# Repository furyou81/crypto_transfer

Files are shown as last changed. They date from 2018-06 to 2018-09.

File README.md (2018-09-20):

# crypto_transfer project

crypto transfert is a cryptocurrency payment terminal that we designed from scratch:
  - selecting the components and the PIC32
  - schematics and designing the PCB with Altium
  - coding the drivers (I2C, SPI, UART, ... ) in C with Mplab
  - coding the server with Node JS to interact with the Ethereum blockchain
  - coding a hotspot interface in PHP to configure the wifi on the payment terminal
  - proof of concept then prototyping
  - designing the case with Fusion 360

# Some pictures of the project

## Box
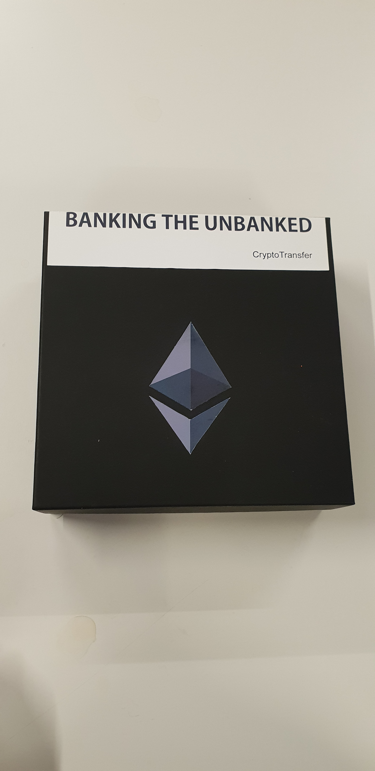
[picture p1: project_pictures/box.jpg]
Box


## Card
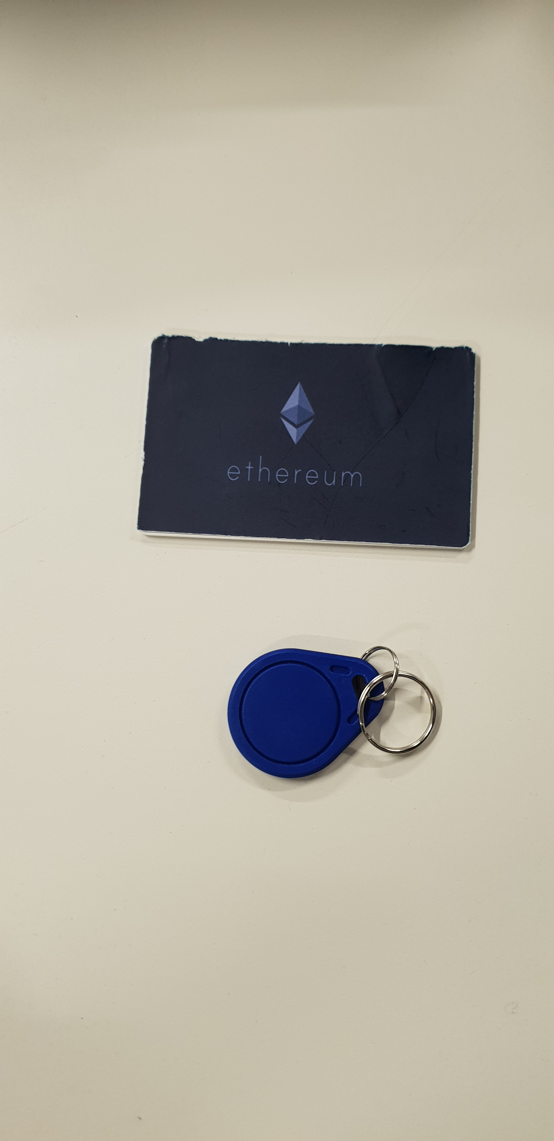
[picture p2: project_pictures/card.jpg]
Card


## Face
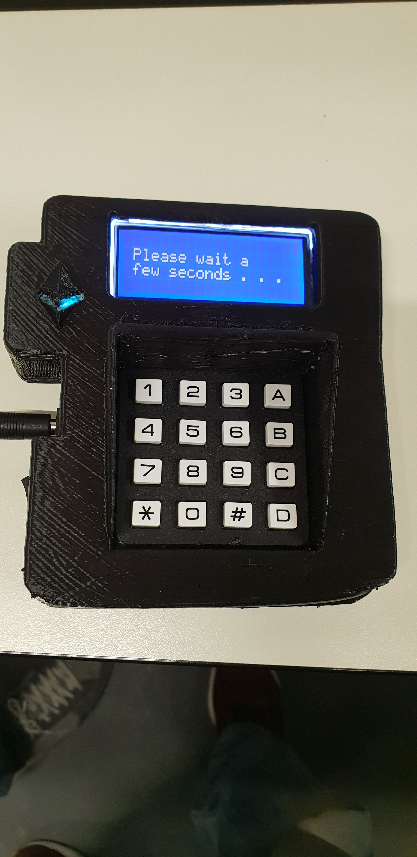
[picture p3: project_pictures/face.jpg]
Face


## Bottom
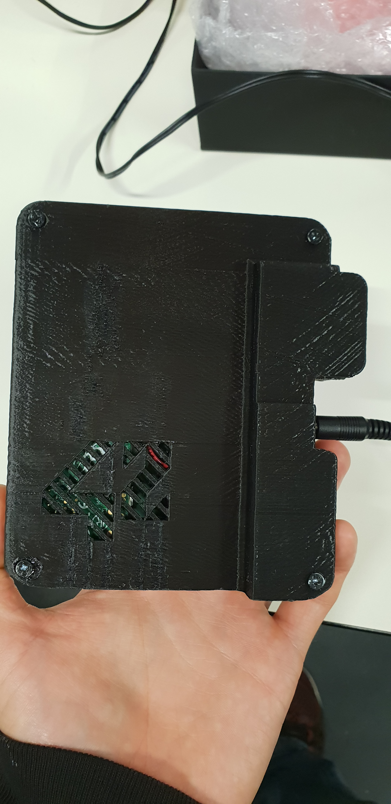
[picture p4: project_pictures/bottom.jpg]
Bottom


## Menu
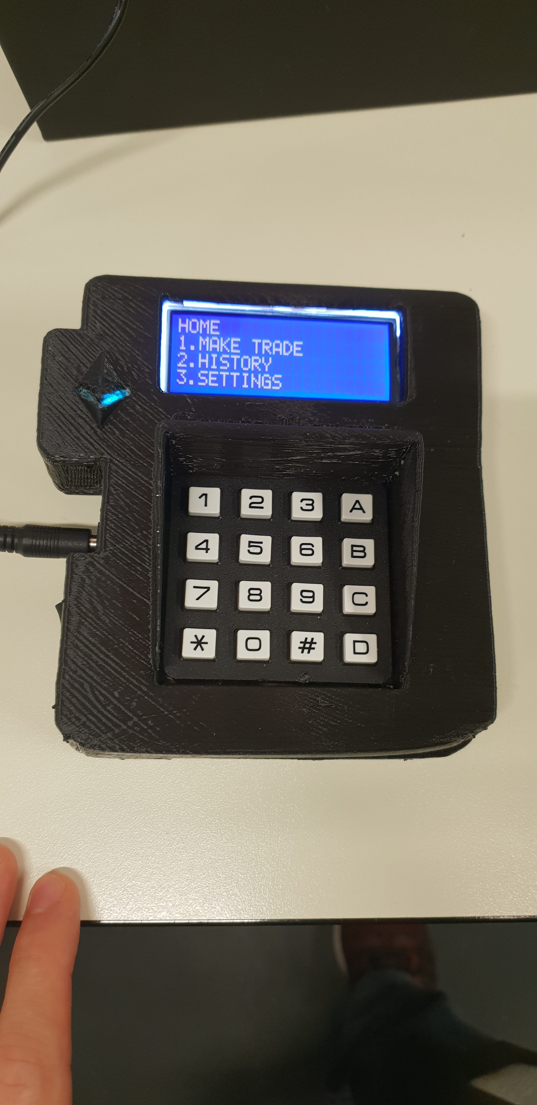
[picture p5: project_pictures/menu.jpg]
Menu


## PCB
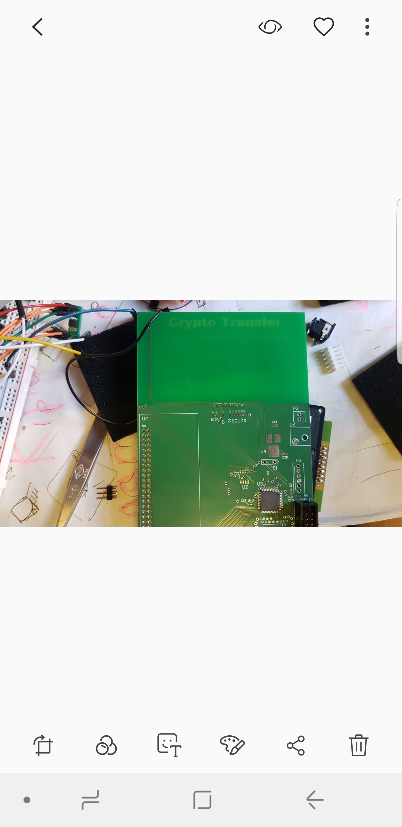
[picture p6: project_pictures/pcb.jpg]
PCB


## PCB with components
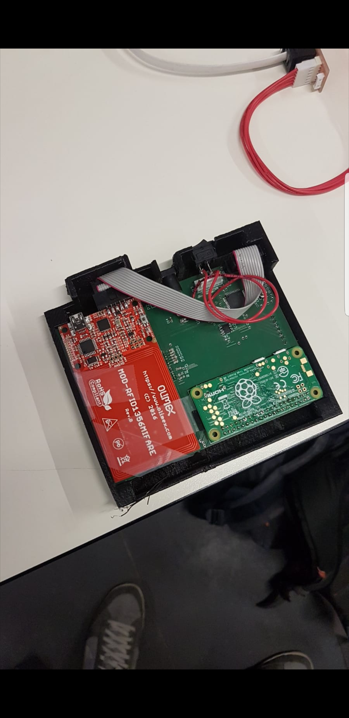
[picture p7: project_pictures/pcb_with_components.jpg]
PCB with components


## 3D design with Fusion 360
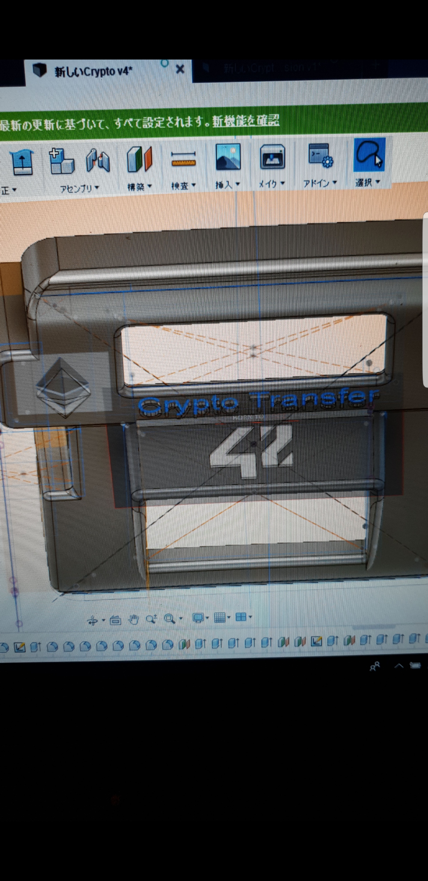
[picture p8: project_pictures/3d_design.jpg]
3D design


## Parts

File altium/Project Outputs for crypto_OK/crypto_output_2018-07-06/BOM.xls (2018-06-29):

Designator | Comment | FABRIQUANT | FOURNISSEUR | REF FABRIQUANT | REF FOURNISSEUR
P3 | ISCP | Molex | Farnell | 22-29-2061 | 1360134 | a commander
P4 | UEXT connector | OLIMEX | OLIMEX | MOD-RFID1356MIFARE | MOD-RFID1356MIFARE | a commander
U1 | ledRGB | MIDAS | FARNELL | AMB-MTB0-0A3A2 | 2401105
U2 | Flash | MICROCHIP | FARNELL | SST25VF010A-33-4C-SAE | 1829949
U3 | PIC32_1 | MICROCHIP | FARNELL | 2456845 | PIC32MX170F256D-I/PT | a commander
U4 | regulateur | TEXAS INSTRUMENTS | FARNELL | LM1117DT-3.3/NOPB | 1469048 | a commander
U5 | clavier | MULTICOMP | FARNELL | MCAK1604NBWB | 1182239
U6 | alim | Lumberg | Farnell | 1613 09 | 1216991 | a commander
U7 | Raspberry_pi_zero_w |  |  | X
C1 | Cap
C2 | Cap
C3 | Cap
C4 | Cap
C5 | Cap
C6 | Cap
C7 | Cap
C8 | Cap
C9 | Cap
C10 | Cap
C11 | Cap
C13 | Cap
C17 | Cap
C18 | Cap
C19 | Cap
C21 | Cap
Y1 | Quartz 8MHz | FOX ELECTRONICS | FARNELL | FOXSDLF/080-20 | 2063972 | a commander
P2 | lcd backlight | PHOENIX CONTACT | Farnell | 1725656 | 3041359 | a commander
P1 | LCD | MIDAS | FARNELL | MCCOG42005A6W-BNMLWI | 2218946
C14 | capacite ceramique | TDK | FARNELL | C1608X5R0J106K080AB | 2346889 | a commander
C20 | capacite ceramique | TDK | FARNELL | C1608X5R0J106K080AB | 2346889 | a commander
R1 | Res2
R2 | Res2
R3 | Res2
R4 | Res2
R5 | Res2
R6 | Res2
R7 | Res2
 | Connecteur RFID | AMP - TE CONNECTIVITY | FARNELL | 1761681-3 | 1772799 | a commander
 | Barrette clavier | MULTICOMP | FARNELL | 2211S-08G | 1593416 | a commander
 | Alimentation | XP POWER | FARNELL | ACM PLUG EU | 2674846 | a commander
 | Alimentation | XP POWER | FARNELL | ACM18US05 | 2671551 | a commander

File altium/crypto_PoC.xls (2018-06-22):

Designator | Comment | FABRIQUANT | FOURNISSEUR | REF FABRIQUANT | REF FOURNISSEUR
U1 | RFID | OLIMEX | FARNELL | MOD-RFID1356MIFARE | MOD-RFID1356MIFARE
U2 | Flash refdu comp | MICROCHIP | FARNELL | SST25VF010A-33-4C-SAE | 1829949
U3 | Raspberry_pi_zero_w |  |  | X
U4 | clavier | MULTICOMP | FARNELL | MCAK1604NBWB | 1182239
C1 | Cap
C2 | Cap
C3 | Cap
C4 | Cap
C5 | Cap
C6 | Cap
C7 | Cap
C8 | Cap
P1 | LCD Connector | MIDAS | FARNELL | MCCOG42005A6W-BNMLWI | 2218946
R1 | Res2
R2 | Res2
R3 | Res2
R4 | Res2
R5 | Res2
R6 | Res2
R7 | Res2
R8 | Res2
R9 | Res2
RGB | LEDRBG | BROADCOM LIMITED | FARNELL | ASMB-MTB0-0A3A2 | 2401105

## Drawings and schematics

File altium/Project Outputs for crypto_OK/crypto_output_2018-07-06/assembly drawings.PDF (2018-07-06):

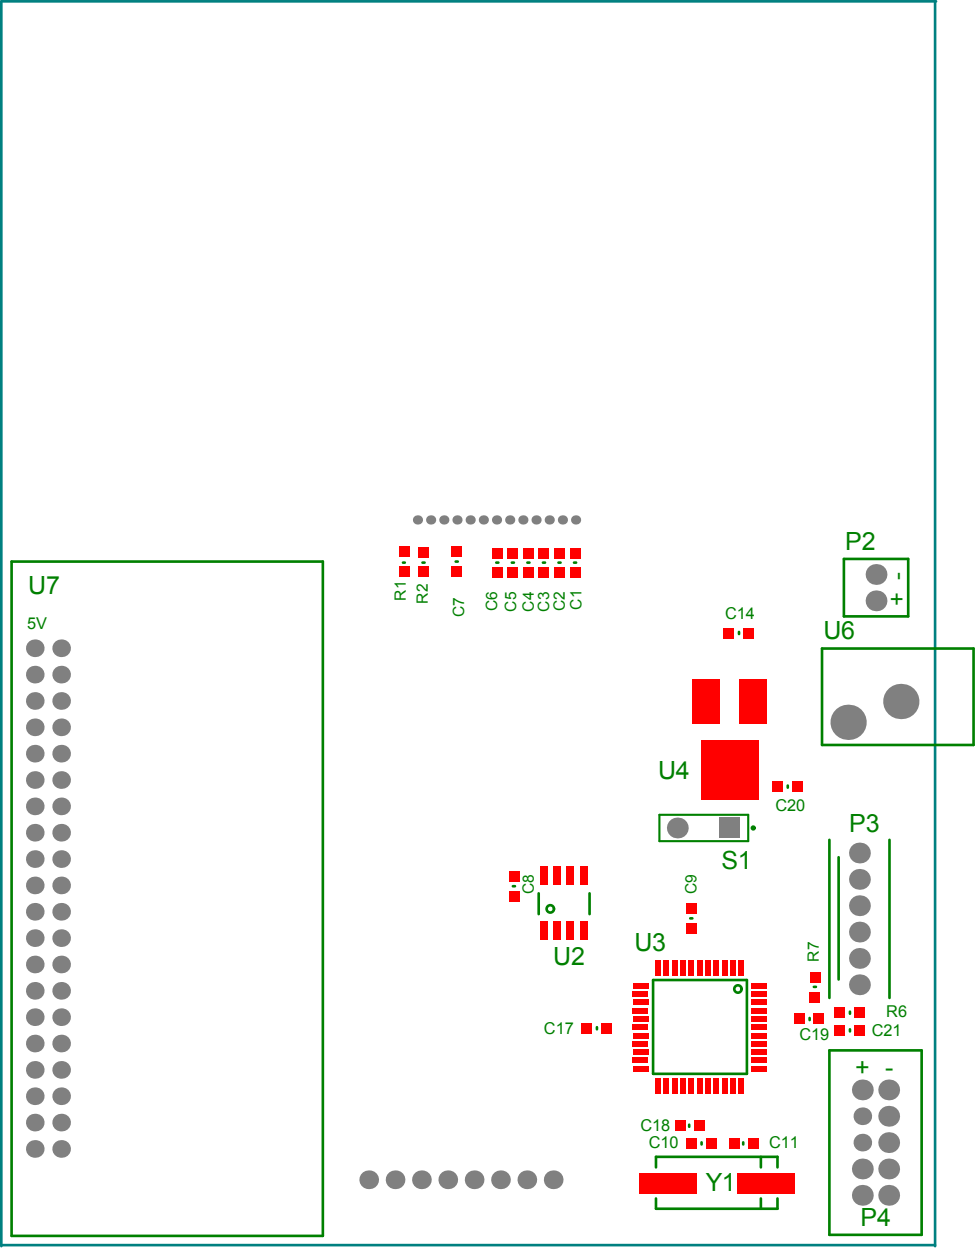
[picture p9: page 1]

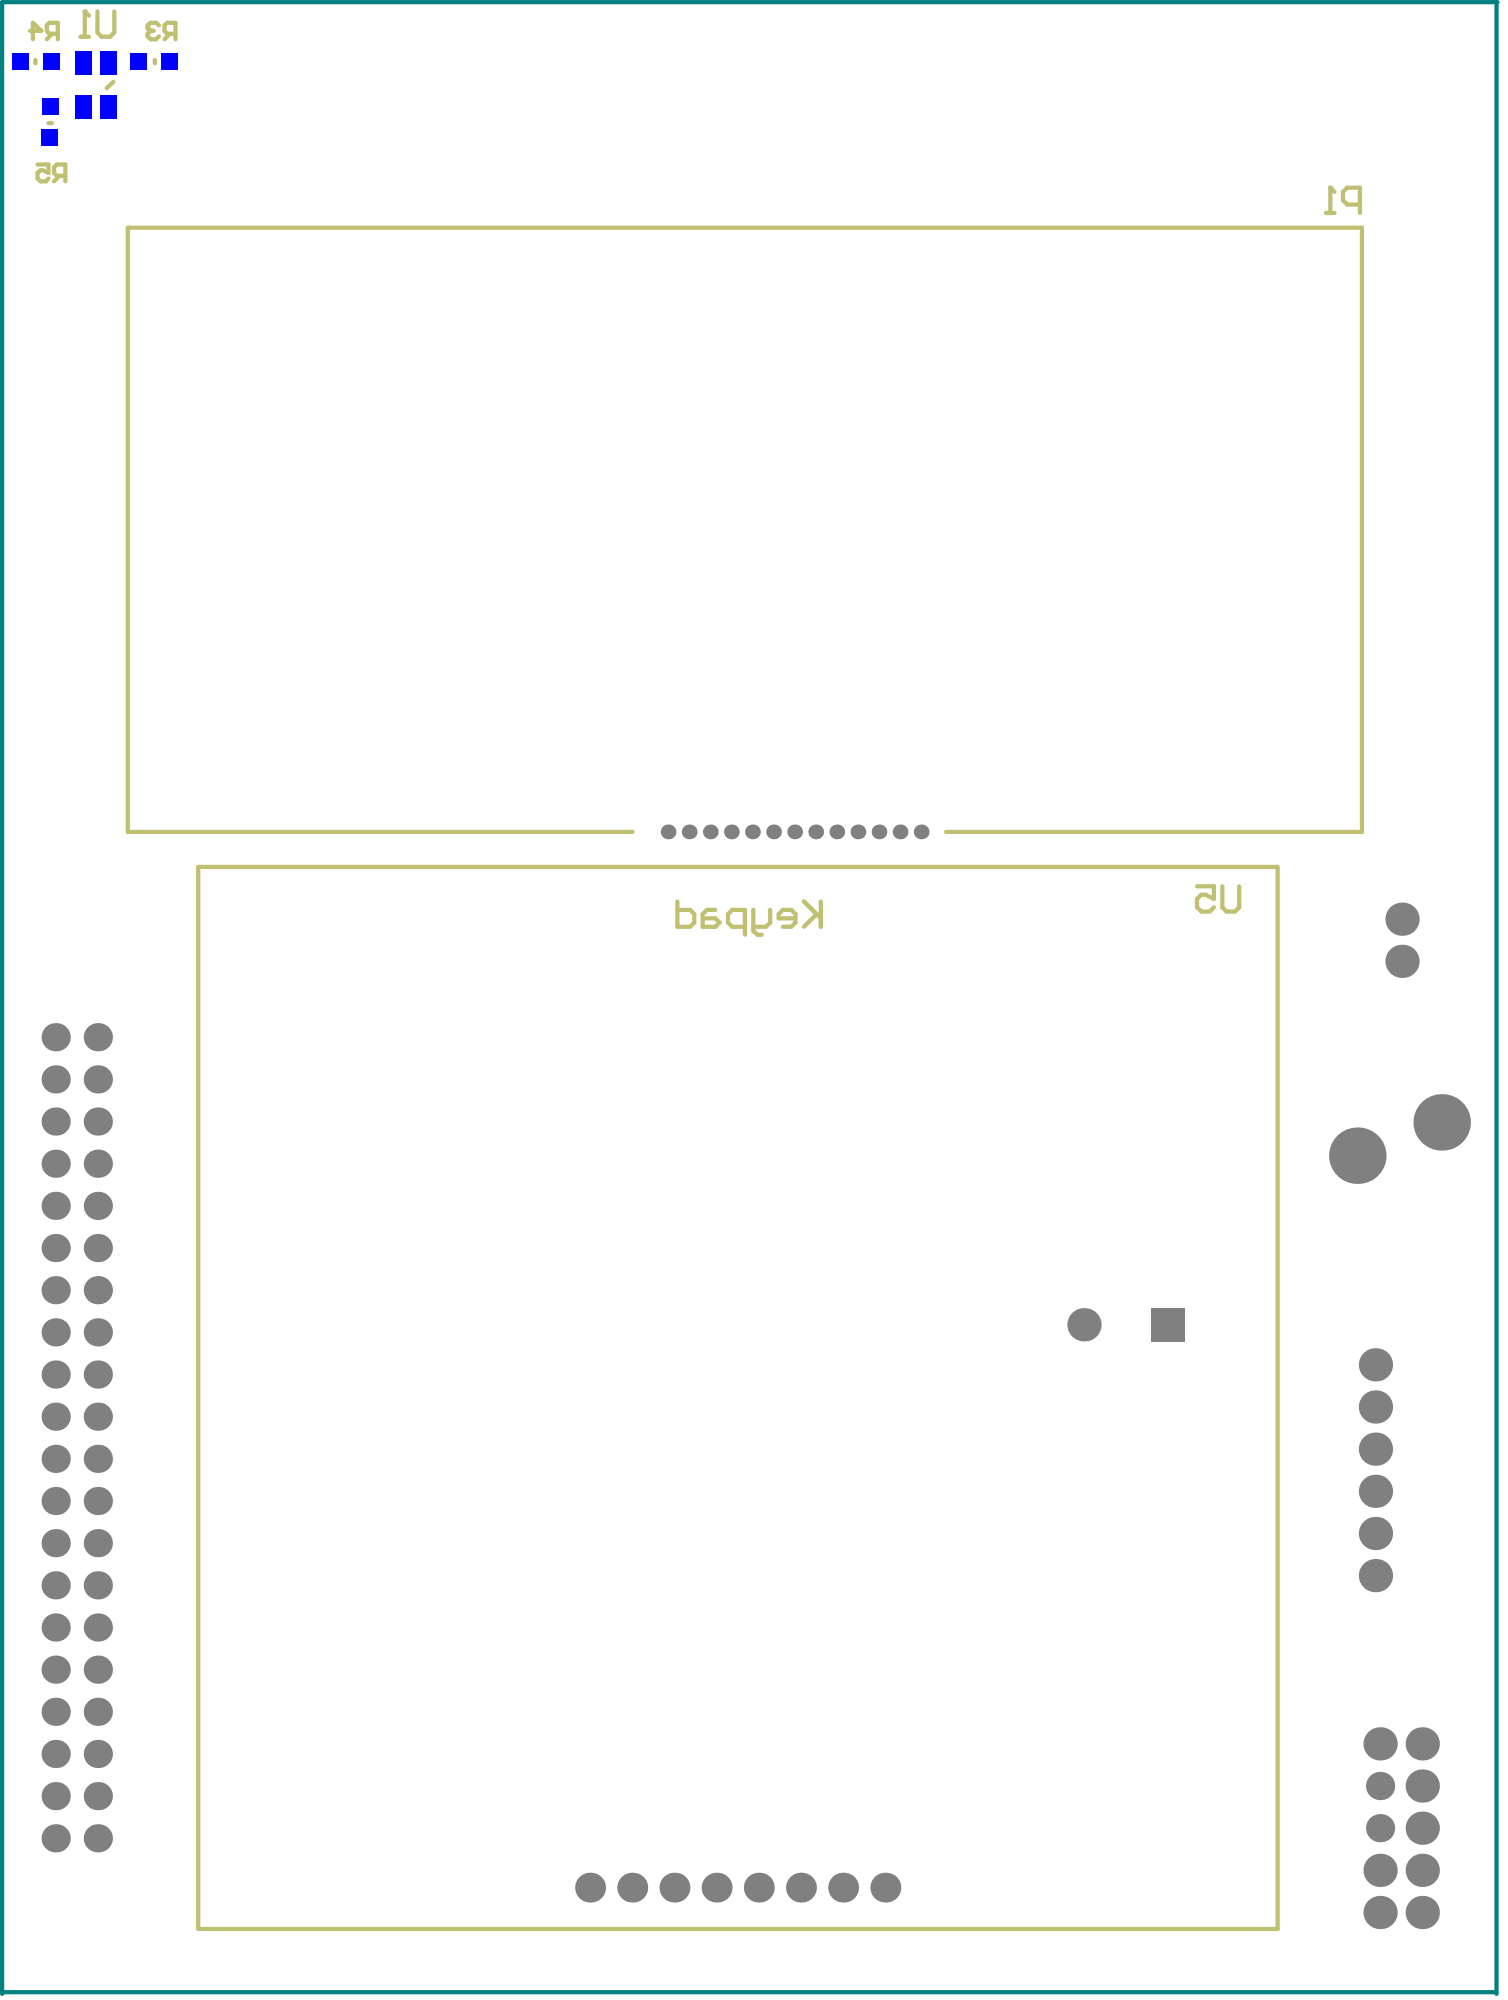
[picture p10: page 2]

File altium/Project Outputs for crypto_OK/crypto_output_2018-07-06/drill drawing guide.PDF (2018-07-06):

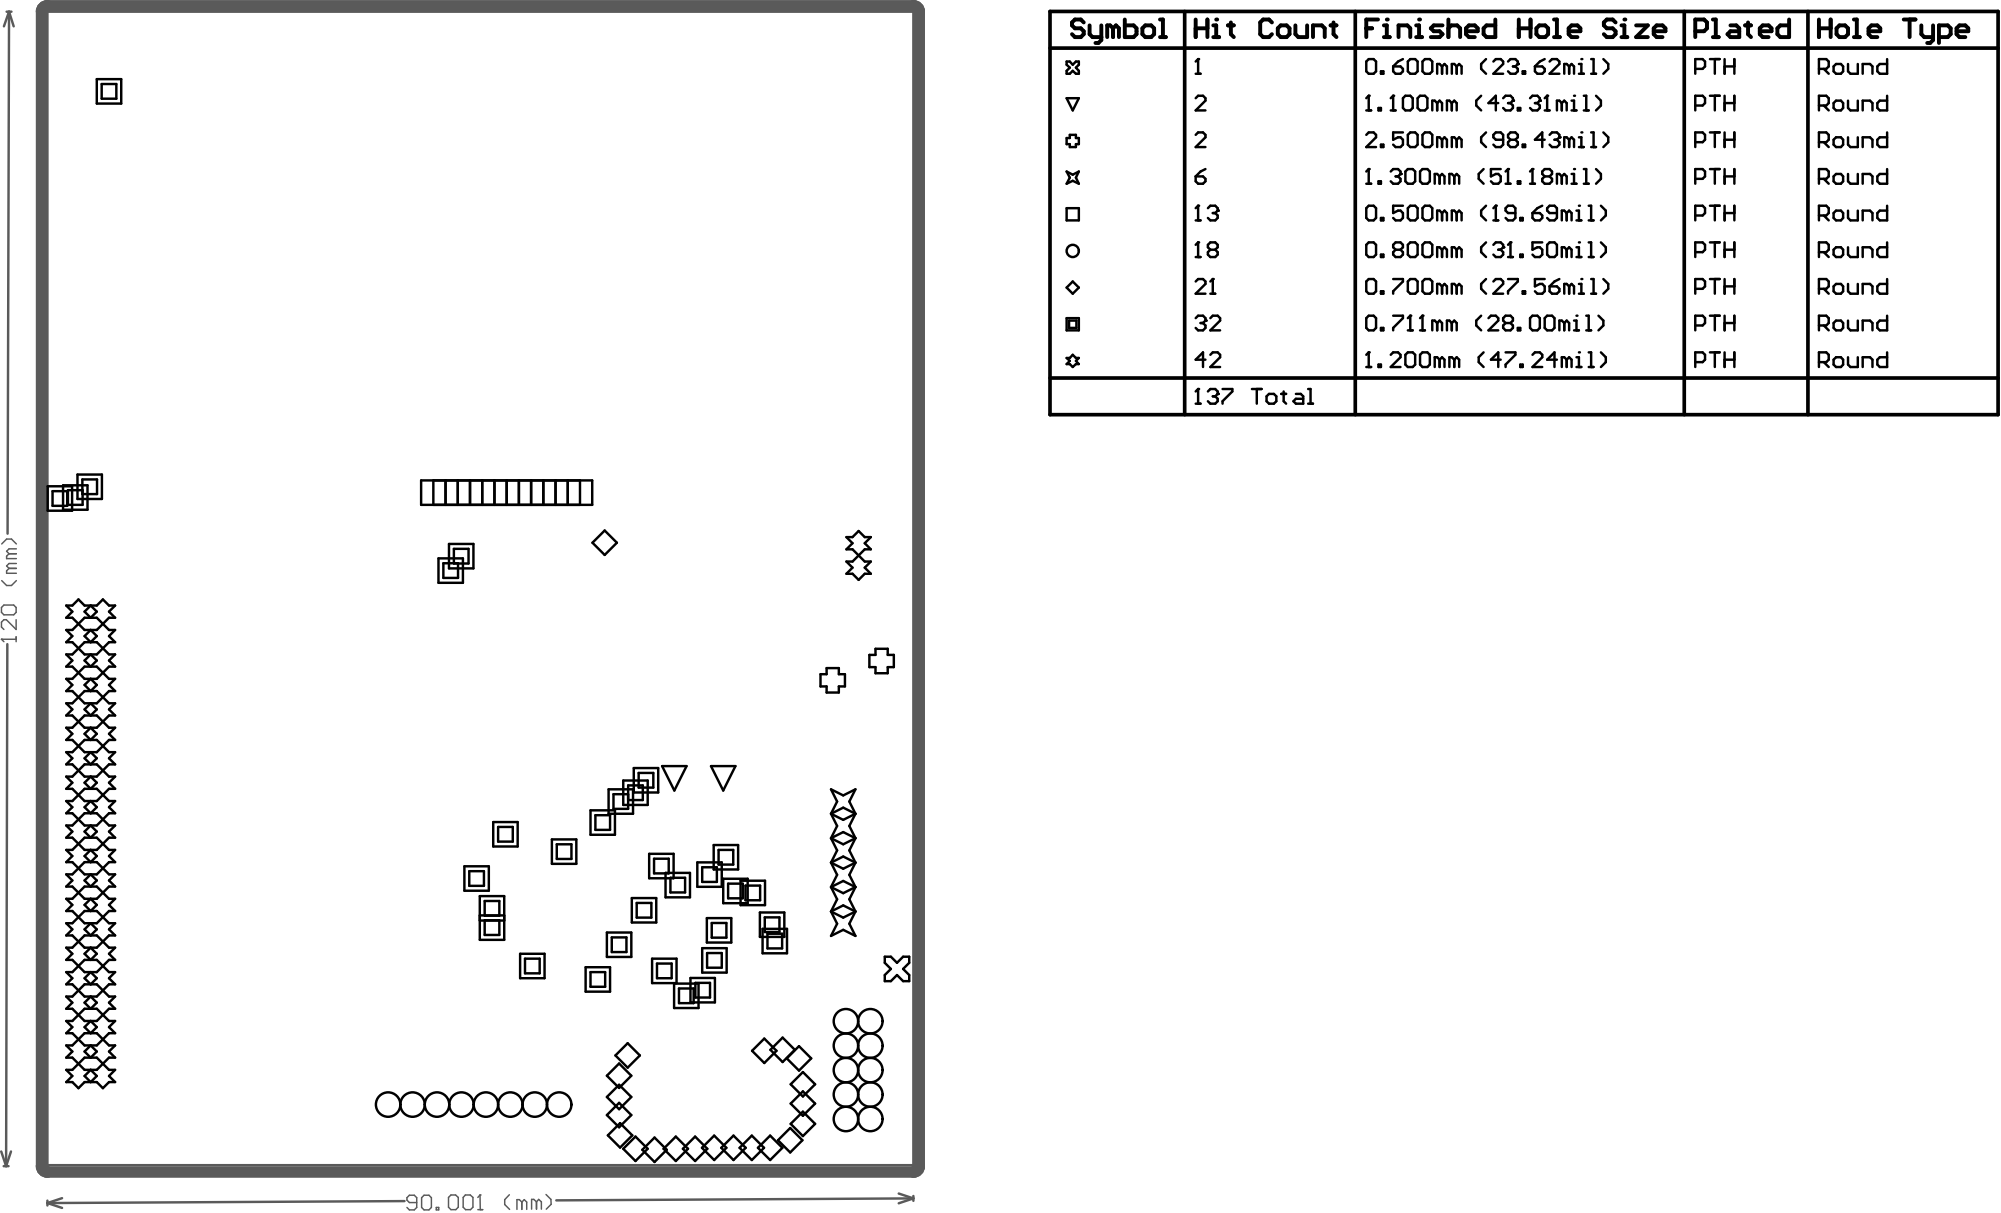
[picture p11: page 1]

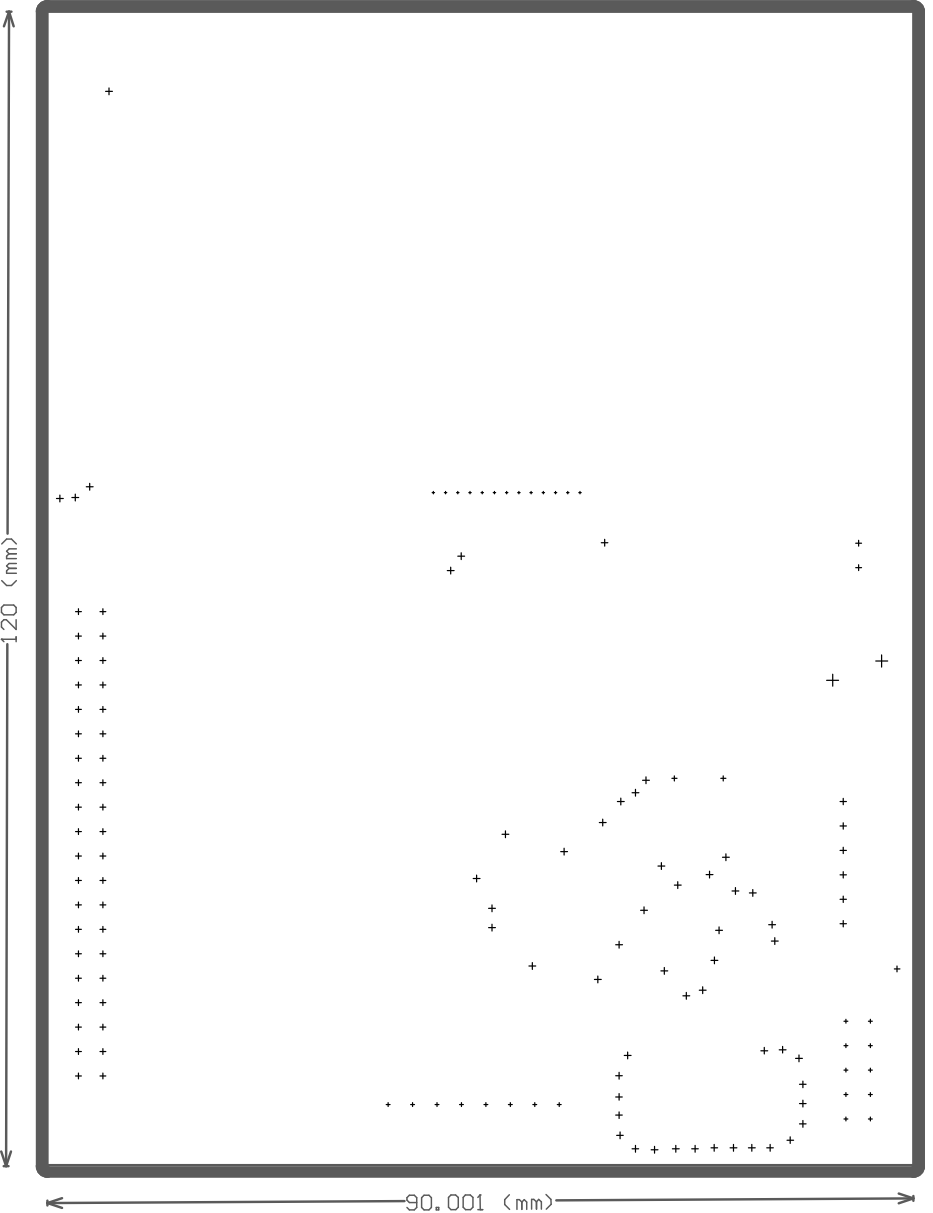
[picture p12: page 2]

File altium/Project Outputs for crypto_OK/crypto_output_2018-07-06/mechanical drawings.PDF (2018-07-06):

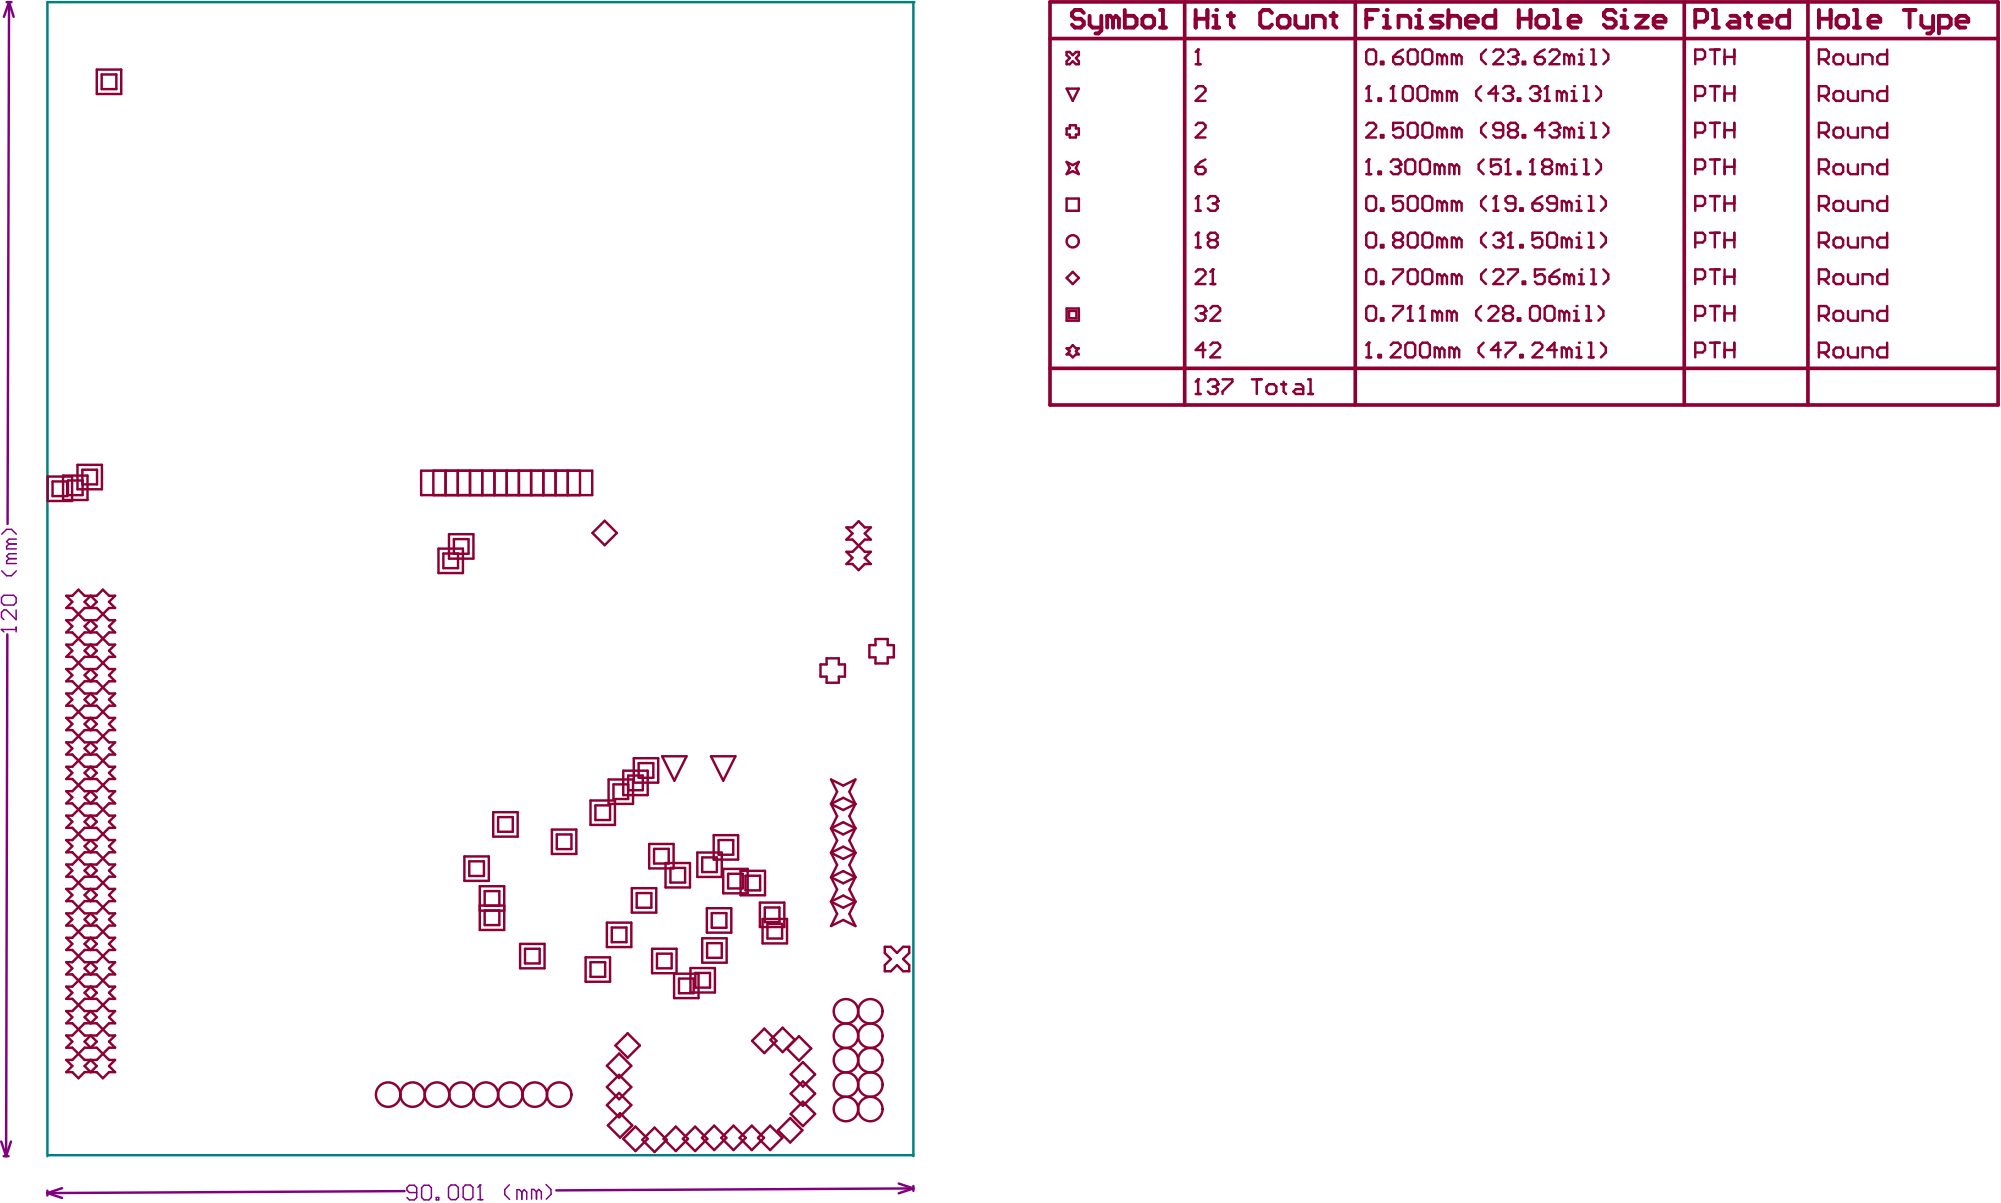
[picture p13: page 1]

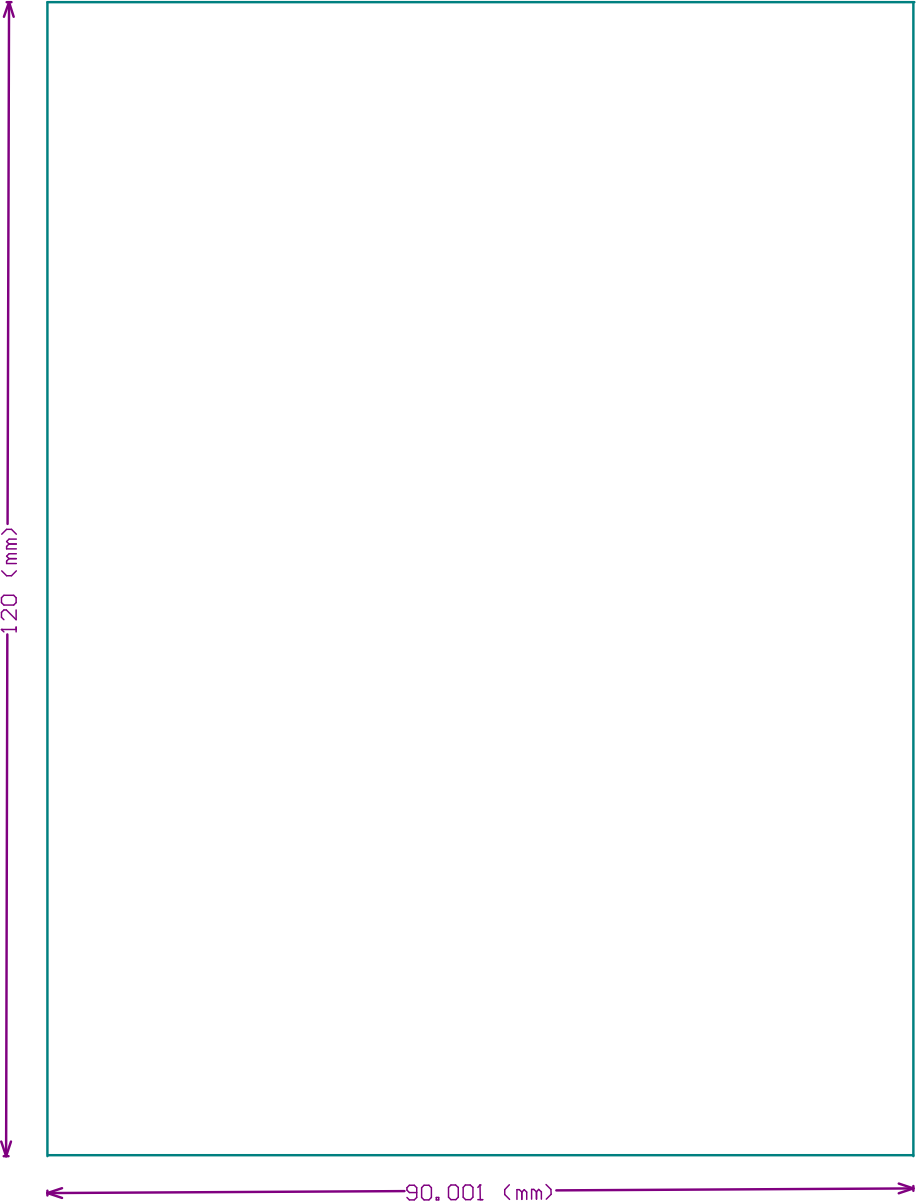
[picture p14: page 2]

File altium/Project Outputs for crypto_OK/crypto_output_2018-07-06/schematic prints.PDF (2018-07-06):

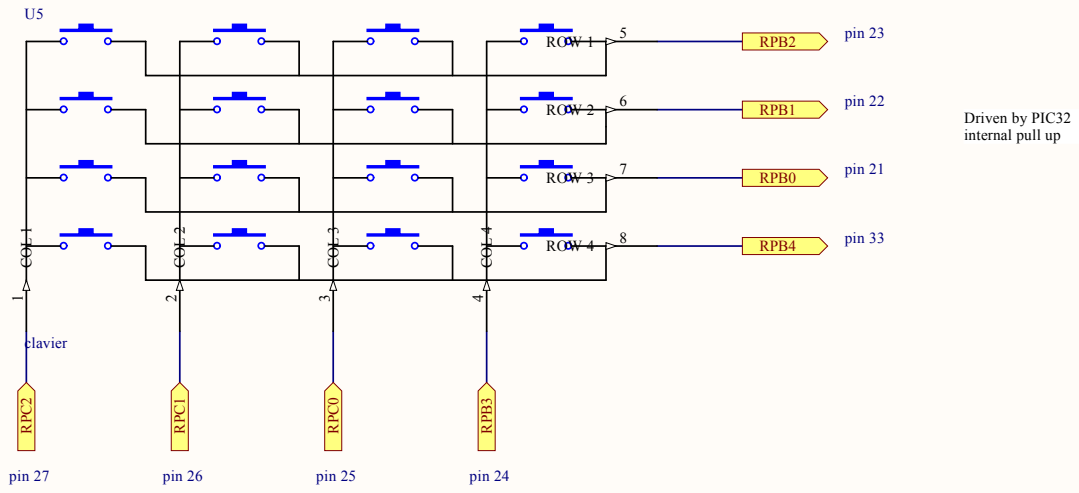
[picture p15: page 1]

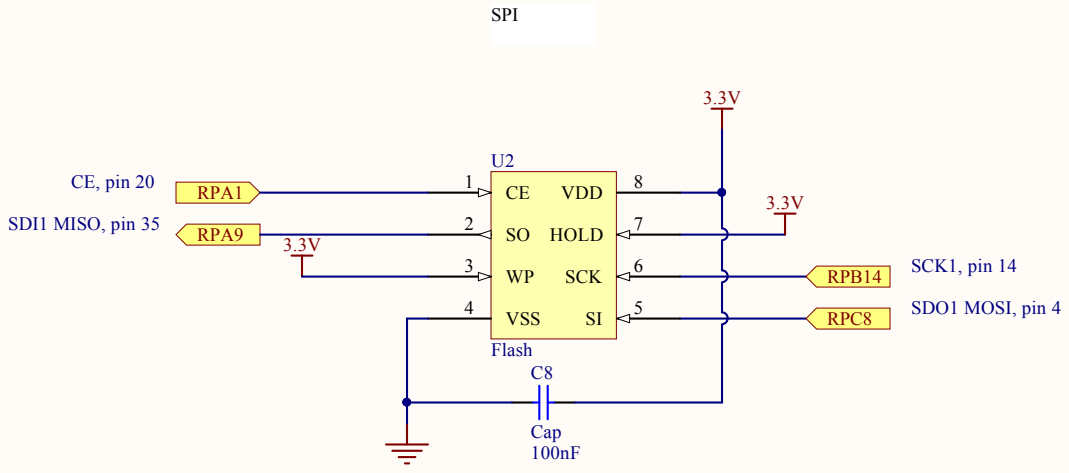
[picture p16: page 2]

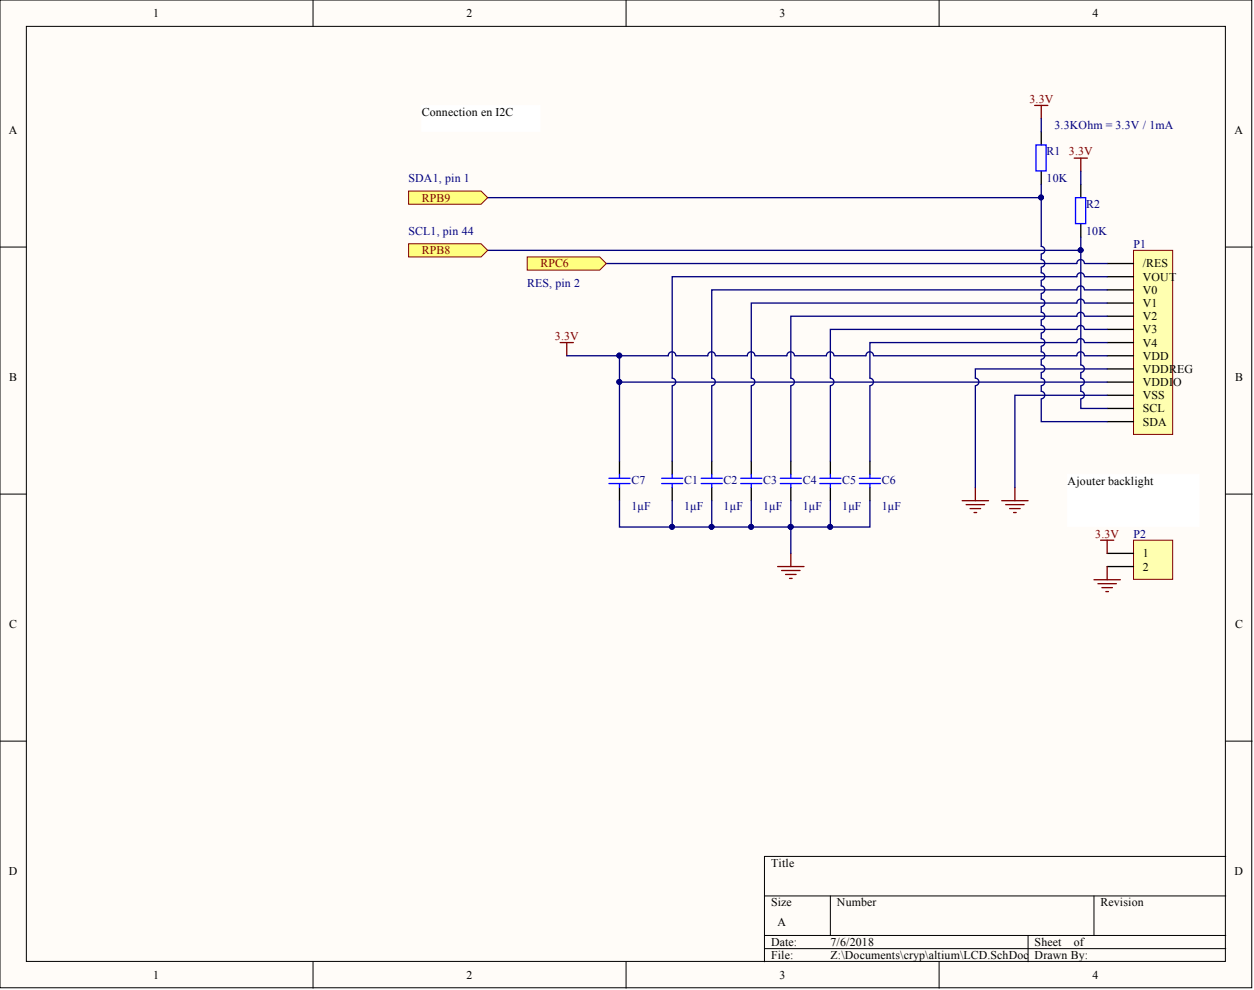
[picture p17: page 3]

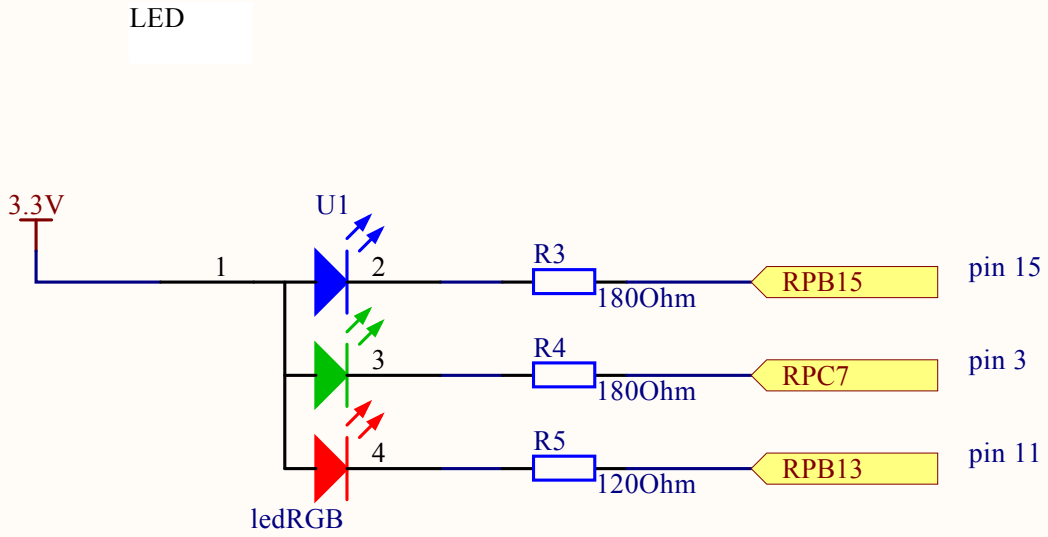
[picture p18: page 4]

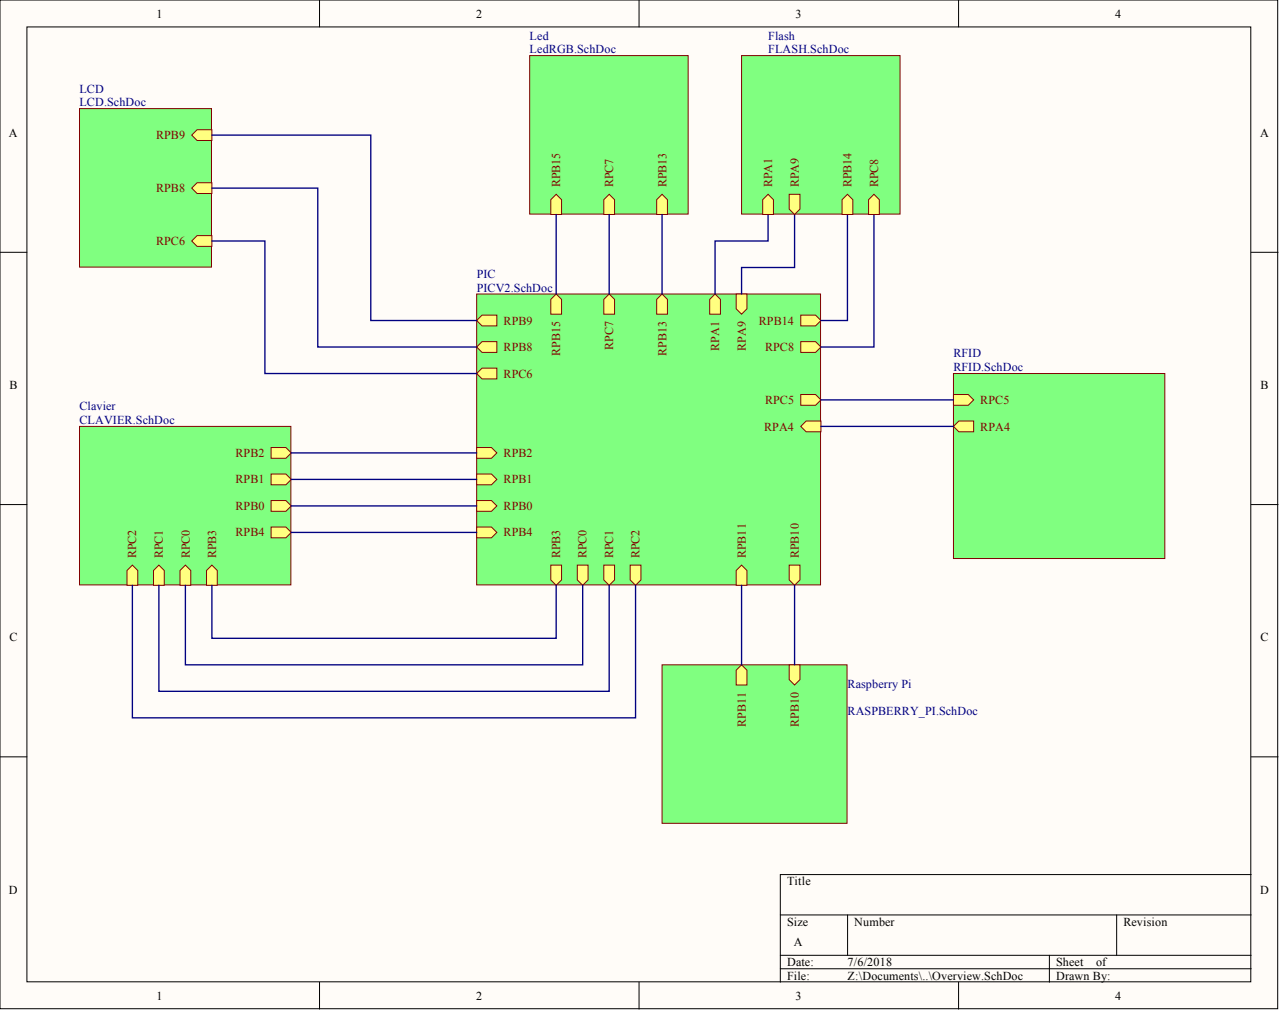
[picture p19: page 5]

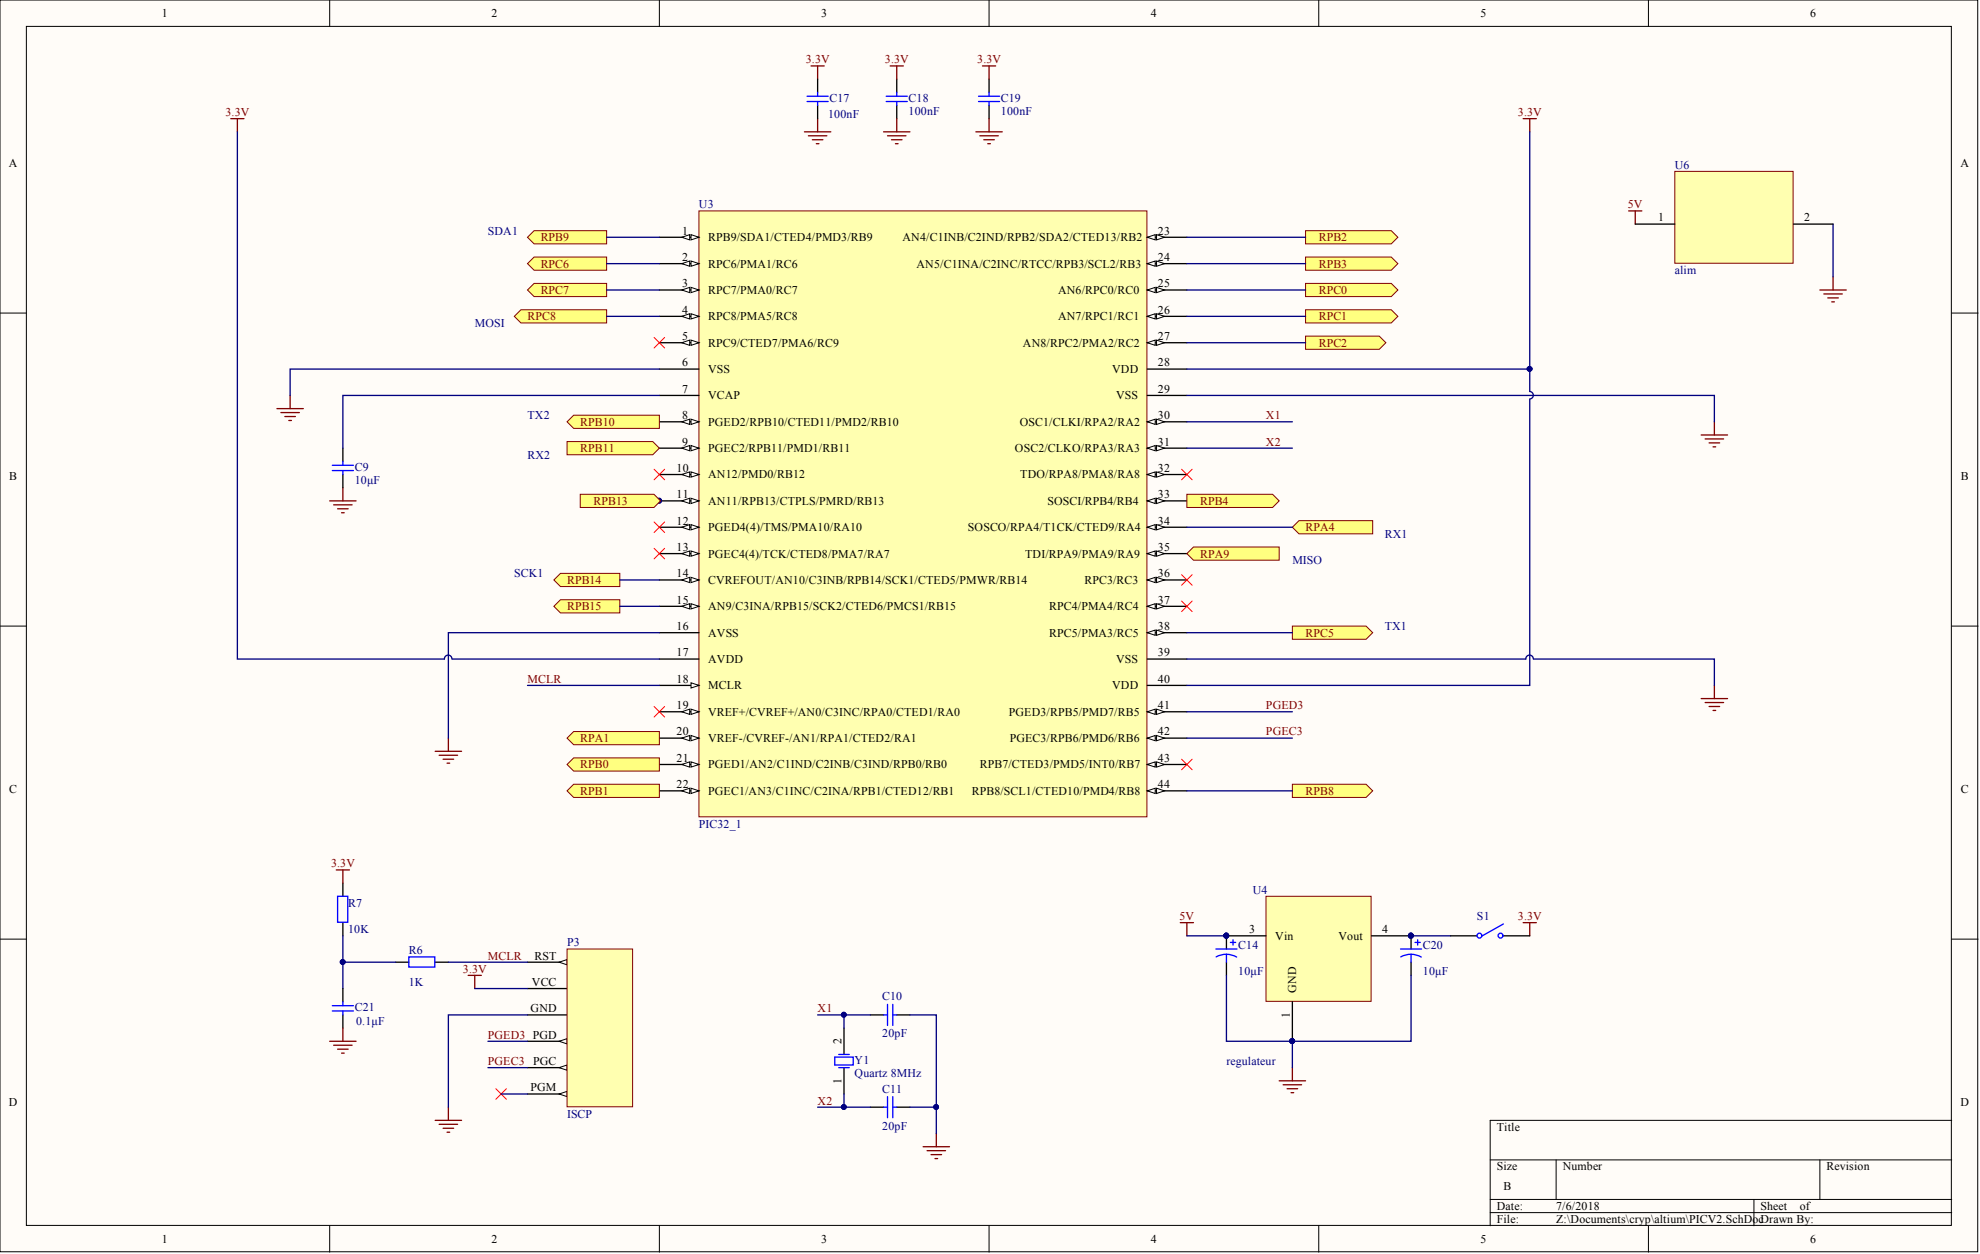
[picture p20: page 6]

TX2 RPB10 | | X1

X2 RPA4 RX1 MISO TX1 RPC5

C9 | RX2 RPB13 SCK1 RPB14 RPB15 | RPB4



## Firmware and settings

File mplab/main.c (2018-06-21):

/*
 * File:   main.c
 * Author: bocal
 *
 * Created on May 20, 2018, 3:28 PM
 */
#pragma config FPLLIDIV = DIV_2         // PLL Input Divider (2x Divider)
#pragma config FPLLMUL = MUL_20         // PLL Multiplier (20x Multiplier)
#pragma config FPLLODIV = DIV_4         // System PLL Output Clock Divider (PLL Divide by 4)

// DEVCFG1
#pragma config FNOSC = FRCPLL           // Oscillator Selection Bits (Fast RC Osc with PLL)
#pragma config FSOSCEN = OFF            // Secondary Oscillator Enable (Disabled)
#pragma config IESO = OFF               // Internal/External Switch Over (Disabled)
#pragma config POSCMOD = OFF            // Primary Oscillator Configuration (Primary osc disabled)
#pragma config OSCIOFNC = ON            // CLKO Output Signal Active on the OSCO Pin (Enabled)
#pragma config FPBDIV = DIV_1           // Peripheral Clock Divisor (Pb_Clk is Sys_Clk/1)
#pragma config FCKSM = CSDCMD           // Clock Switching and Monitor Selection (Clock Switch Disable, FSCM Disabled)
#pragma config WDTPS = PS1048576        // Watchdog Timer Postscaler (1:1048576)
#pragma config FWDTEN = OFF             // Watchdog Timer Enable (WDT Disabled (SWDTEN Bit Controls))

// DEVCFG0
#pragma config DEBUG = OFF              // Background Debugger Enable (Debugger is disabled)
#pragma config ICESEL = ICS_PGx2        // ICE/ICD Comm Channel Select (ICE EMUC2/EMUD2 pins shared with PGC2/PGD2)
#pragma config PWP = OFF                // Program Flash Write Protect (Disable)
#pragma config BWP = OFF                // Boot Flash Write Protect bit (Protection Disabled)
#pragma config CP = OFF                 // Code Protect (Protection Disabled)

#include "crypto.h"

int main(void)
{
    TMR2 = 0;
    T2CONbits.ON = 1;
    init_uart_rfid(); // communication avec le lecteur rfid
    init_uart(); // communication avec la raspberry pi
  
    start_transaction(45896);
    TMR2 = 0;
    while (TMR2 < 10000);
    TMR2 = 0;
    while (TMR2 < 10000);
    TMR2 = 0;
    while (TMR2 < 10000);
    TMR2 = 0;
    while (TMR2 < 10000);
    TMR2 = 0;
    while (TMR2 < 10000);
    TMR2 = 0;
    while (TMR2 < 10000);
    TMR2 = 0;
    while (TMR2 < 10000);
    TMR2 = 0;
    while (TMR2 < 10000);
    TMR2 = 0;
    while (TMR2 < 10000);
    TMR2 = 0;
    while (TMR2 < 10000);
    TMR2 = 0;
    while (TMR2 < 10000);
//    start_transaction(785);
    while(1)
    {
        ;
    }
    return (EXIT_SUCCESS);
}

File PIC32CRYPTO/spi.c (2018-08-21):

/*
 * File:   lcd_I2C.c
 * Author: bocal
 *
 * Created on May 20, 2018, 3:28 PM
 */

#include "crypto.h"

#define READID 0x90
#define RDSR 0x05
#define WRITE  0x02
#define READ   0x03
#define WREN 0x06
#define WRDI 0x04
#define EWSR 0x50
#define WRSR 0x01
#define ERRASE 0x60
#define SECTOR_ERRASE 0x20

#define ADD_MANUFACTURER 0x00
#define ADD_DEVICE 0x01



void on()
{
    LATAbits.LATA1 = 0; //  The device is enabled by a high to low transition on CE#. CE# must remain low for the duration of any command sequence.
}

void off()
{
    LATAbits.LATA1 = 1;
}

void initSPI(void)
{
    TRISAbits.TRISA1 = 0;		// CE / CS
    on();						// Set CS high (idle state)
	SDI1R = 0b0111;				// SDI1 MISO RPA9
	RPC8R = 0b0011;				// SDO1 MOSI RPC8
    IEC1bits.SPI1EIE = 0;       // SPI interrupts disabled
    IEC1bits.SPI1RXIE = 0;
    IEC1bits.SPI1TXIE = 0;

    SPI1CONbits.ON = 0;         // Turn off SPI module

    SPI1BUF = 0;                // Clear the receive buffer

    SPI1BRG = 3;                // FSCK = 2.5MHz

    SPI1STATbits.SPIROV = 0;    // Clear overflow flag


    /* SPI1CON settings */
    SPI1CONbits.FRMEN = 0;      // Framed SPI support is disabled
    SPI1CONbits.SIDL = 0;       // Continue operation in IDLE mode
    SPI1CONbits.DISSDO = 0;     // SDO1 pin is controlled by the module
    SPI1CONbits.MODE16 = 0;     // 8 bit mode
    SPI1CONbits.MODE32 = 0;     // 8 bit mode
    SPI1CONbits.CKP = 1;        // Idle state for clock is high, active state is low
    SPI1CONbits.CKE = 0;        // Output data changes on transition from idle to active
    SPI1CONbits.SSEN = 0;       // Not in slave mode
    SPI1CONbits.MSTEN = 1;      // Master mode
    SPI1CONbits.SMP = 1;        // Input data sampled at the end of data output time

    SPI1CONbits.ON = 1;         // Turn module on
    off();
}

u8 rSPI(u8 data)
{
    SPI1STATbits.SPIROV = 0;		// reset overflow flag
    while (!SPI1STATbits.SPITBE);	// while buf is not empty wait
    SPI1BUF = data;
    while (!SPI1STATbits.SPIRBF);	// Wait for transfer to be completed
    return (SPI1BUF);
}

u8 read_status()
{
    u8 status;
    on();
    rSPI(RDSR);
    status = rSPI(0x78); // nimporte quoi
    base(status);
    off();
    return (status);
}

u8 read_status_uart()
{
    u8 status;
    on();
    rSPI(RDSR);
    status = rSPI(0x78); // nimporte quoi
    off();
    return (status);
}

void wait_ready()
{
    u8 stat;

    stat = read_status_uart();
    while (stat & 0x01)
        stat = read_status_uart();
}

u8 readID()
{
    volatile u8 trash;
    u8 d;

    on();
    trash = rSPI(READID);
    trash = rSPI(0x0);
    trash = rSPI(0x0);
    trash = rSPI(ADD_MANUFACTURER);
    d = rSPI(0x8);
    off();
    base(d);
    return (d);
}

void change_status2()
{
    on();
    rSPI(WRDI); // disable write
    //while(SPI2STATbits.SPIBUSY);
    off();
    wait_ready();
    on();
    rSPI(EWSR); //enable chage status
    off();
    //wait_ready();
    //while(SPI2STATbits.SPIBUSY);
    on();
    rSPI(WRSR);
    rSPI(0x00); // clear all bits to enable writting
    off();
    wait_ready();
}

void write_enable()
{
    on();
    rSPI(WREN);
    //while(SPI2STATbits.SPIBUSY);
    off();
}

void sector_erase(u32 adress)
{
    on();
        rSPI(WREN);
    off();
    wait_ready();;
    on();
    rSPI(SECTOR_ERRASE);
    rSPI((adress & (0xFF << 15)) >> 15);
    rSPI((adress & (0xFF << 7)) >> 7);
    rSPI(adress & (0xFF));
    
    off();
	wait_ready();
}


void chiperrase()
{
    on();
    rSPI(WREN);
    off();
    wait_ready();
    on();
    rSPI(ERRASE);
    off();
	wait_ready();

}
void write_disable()
{
    on();
    rSPI(WRDI);
    while(SPI1STATbits.SPIBUSY);
    off();
}

void writeSPI(u8 data, u32 adress)
{
   // chiperrase();
    //sector_erase(adress);
    wait_ready();
    on();
    volatile u8 trash;

   // change_status();
    rSPI(WREN);
    off();
    wait_ready();
    on();
    trash = rSPI(WRITE);
    trash = rSPI((adress & (0xFF << 15)) >> 15);
    trash = rSPI((adress & (0xFF << 7)) >> 7);
    trash = rSPI(adress & (0xFF));
    trash = rSPI(data);
    // while(SPI2STATbits.SPIBUSY);
    //write_disable();
    off();
	wait_ready();
}

u8 readSPI(u32 address)
{
    on();
    u8 tab[50];
    volatile u8 trash;
    trash = rSPI(READ);
    trash = rSPI((address & (0xFF << 15)) >> 15);
    trash = rSPI((address & (0xFF << 7)) >> 7);
    trash = rSPI(address & (0xFF));
    tab[0] = (rSPI(0x04)); // nimporte quoi
    //tab[1] = (rSPI(0x8));
    base(tab[0]);

    off();
    return (0);
}

u8 checkSPI(u32 address)
{
    on();
    u8 tab[50];
    volatile u8 trash;
    trash = rSPI(READ);
    trash = rSPI((address & (0xFF << 15)) >> 15);
    trash = rSPI((address & (0xFF << 7)) >> 7);
    trash = rSPI(address & (0xFF));
    tab[0] = (rSPI(0x04)); // nimporte quoi
    //tab[1] = (rSPI(0x8));

    off();
    return (tab[0]);
}

void	read_zone(u32 depart, u32 fin)
{
	u32 i = depart;
	u8 ret;

	while (i < fin)
	{
		if (i % 20 == 0)
		{
			send_char('|');
			send_char(' ');
		}
		ret = readSPI(i);
		i++;
	}
}

u32		init_adr()
{
	u32 i = 0;
	u32 ret;

	while ((ret = checkSPI(i)) != 0xFF)
		i += 20;
	return (i);
}

void    get_date(u8 trans, u8 date[])
{
    u8 i = 0;
    while (i < 20)
    {
        date[i] = checkSPI(trans * 40 + i);
        i++;
    }
    date[i] = '\0';
}

void    get_amount(u8 trans, u8 tmp[])
{
    u8 i = 0;
    while (i < 20)
    {
        tmp[i] = checkSPI(trans * 40 + i + 20);
        i++;
    }
    tmp[i] = '\0';
}

void	write_line_SPI(u8 str[])
{

	u32 i = 0;

	u32 adress = init_adr();
	while (str[i])
	{
		writeSPI(str[i], adress);
		i++;
		adress++;
	}
	while (i < 20)
	{
		writeSPI(' ', adress);
		adress++;
		i++;
	}
}


u32	count_max_transaction()
{
	u32 ret;
	u32 adr;

	adr = init_adr();
	ret = adr / 40;
	return (ret);
}
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

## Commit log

2018-06-21 spi lcd
2018-06-29 altium soumis a Gregoire
    [BOM.xls, Bill of Materials-crypto_OK.xls, LCD.SchDoc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]
2018-07-05 switch added
    [PCB2.GBL, PCB2.GBO, PCB2.GBP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]
2018-07-05 new pcb
    [PCB2.PcbDoc, PCB3.PcbDoc, PICV2.SchDoc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]
2018-08-17 PIN en cours
2018-08-18 pin marche pas
2018-08-20 uart capricieux dans le sens rasp vers pic, led ok, TODO:implementer set key reader
2018-08-21 changement pin lecteur ok
